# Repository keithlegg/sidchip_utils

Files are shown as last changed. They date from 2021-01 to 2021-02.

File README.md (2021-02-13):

# sidchip_utils

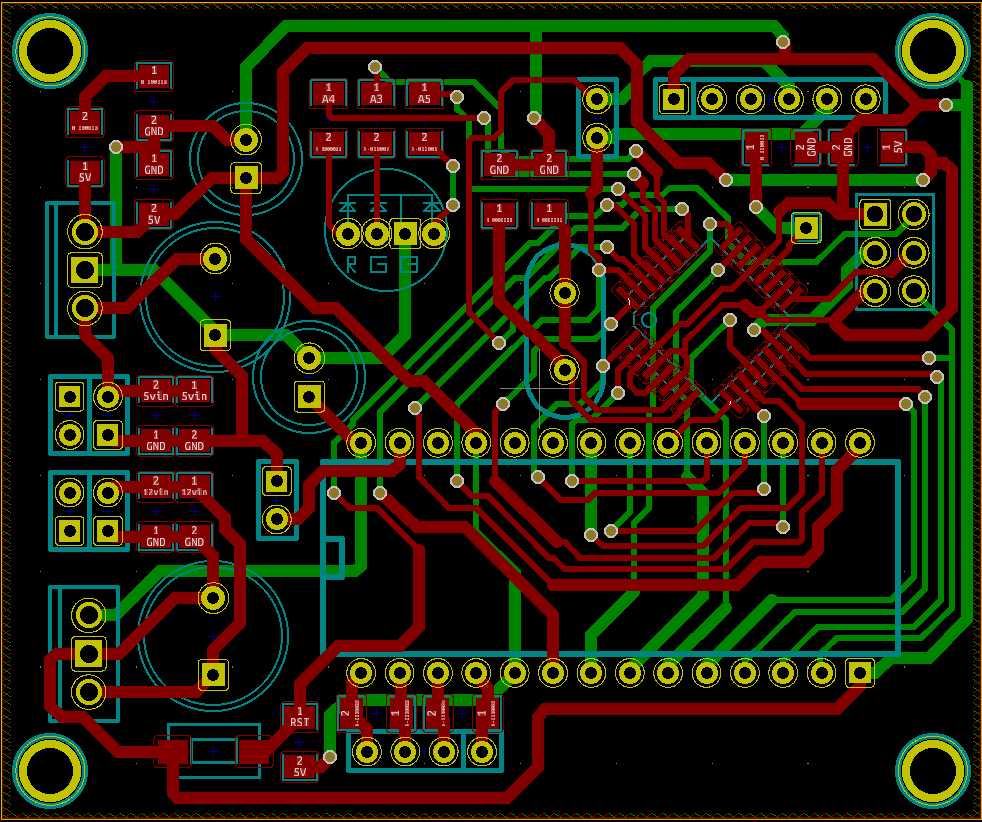
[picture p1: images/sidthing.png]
 

If you ever get the chance to purchase 30 rusty old SID chips from an engineer who worked at Commodore .... 

DONT DO IT! Put your energy into something else.  

This a small collection of tools, references files, and errata making those old chips sing.

What it is:

siduino           - Kicad project / Gerbers 
                    A one off PCB design thats an arduino (atmega328p) that has a SID chip on it 
                    technically you could program it with the arduino tools if you mapped the pins out properly, but I havent tried it has a 12V and 5V power bus to satisfy the analog-y power needs of the old chips. They run hot. 

siduino firmwware - AVR firmware to issue commands to the SID chip from an AtMega328. 
                    There is some experimental assembly language driver and some experimental midi in/out.  

sidcom            - unfinished. A aerial protocol to talk to the SID chip from a modern machine. The board is flawed, the TX/RX
                    pins on the AVR share the lower two bits of the SID chip data bus, so a new board is needed before this can be used. A prototype board is under development. 

python tools      - Havent done anything yet. The RX/TX flaw really makes this board suck. I need to build a better one 
                    with a bigger chip and two SIDs for stereo. maybe someday. 

If you are crazy enough to want to build one yourself (beware this revision has the TX/RX flaw): 

https://oshpark.com/profiles/klegg

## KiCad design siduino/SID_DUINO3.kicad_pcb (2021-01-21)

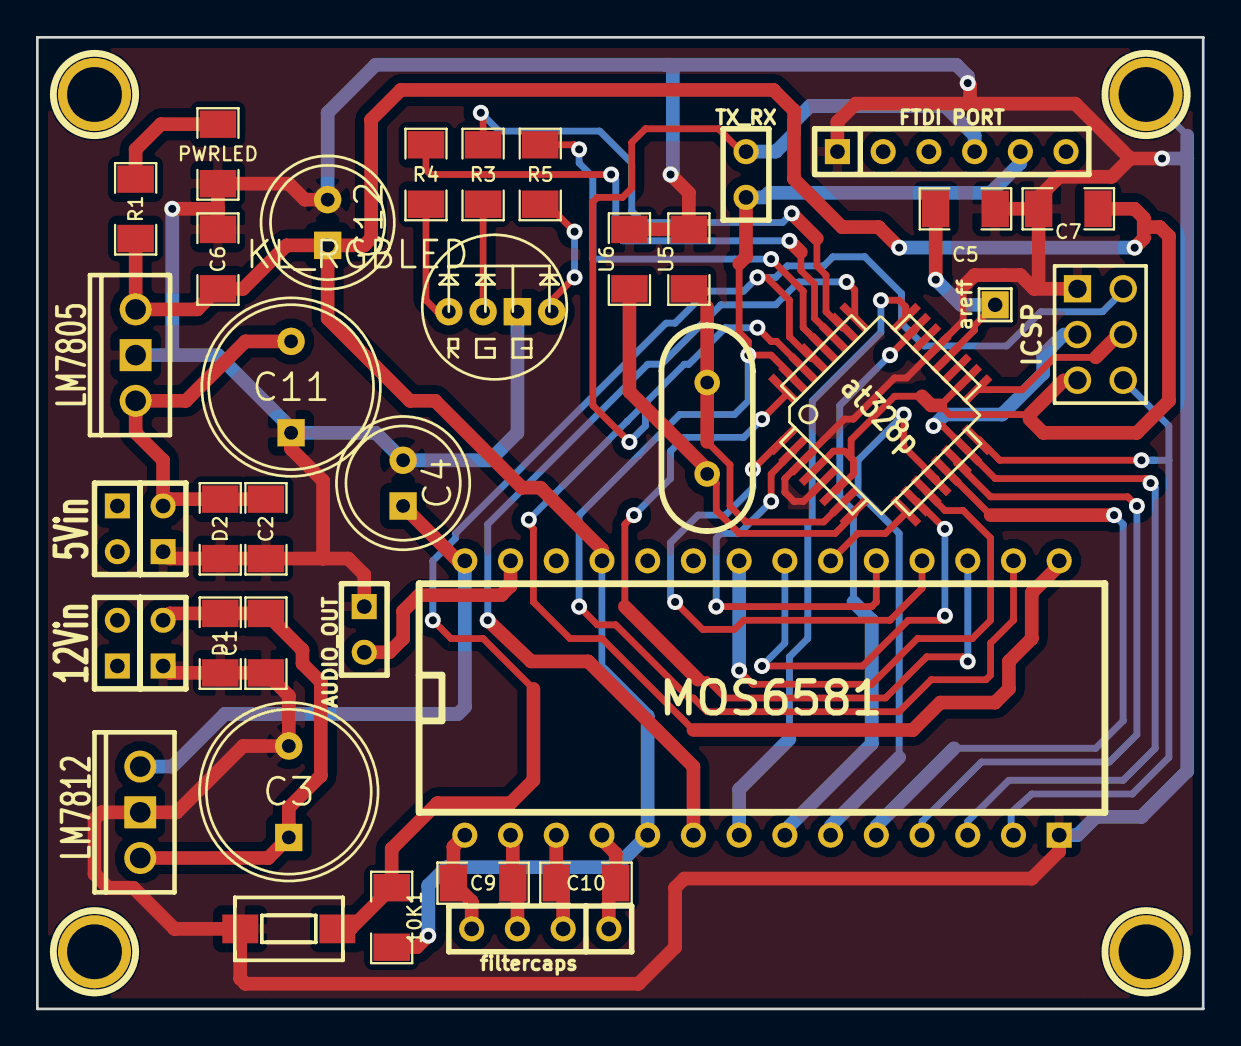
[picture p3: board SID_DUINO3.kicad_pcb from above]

Board: 2 copper layers, 64.8 x 54.0 mm, 30 parts (0 on the bottom side), 21 nets.

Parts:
5Vin: 5V_IN; SIL-2
10K1: R; SM1206
12Vin: 12V_IN; SIL-2
AUDIO_OUT: AudioOut; SIL-2
C1, C2, C5, C9, C10: C; SM1206
C3, C11: KL_330uf
C4, C12: KL_100uf
C6: .1uf; SM1206
C7: 4.7uf; SM1206
D1, D2: DIODE; SM1206
FTDI PORT: FTDI; SIL-6
ICSP: ICSP; pin_array_3x2
PWRLED: LED; SM1206
R1, R3, R4, R5: R; SM1206
TX_RX: UART; SIL-2
U5, U6: 18pf; SM1206
areff: CONN_1; SIL-1
at328p: TQFP32
filtercaps: Val**; SIL-4

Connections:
/5V: 10K1.2, C6.2, C7.1, C12.1, ICSP.2, R1.1, at328p.4, at328p.6, at328p.18
/5vin: 5Vin.2, C2.1, C11.1, D2.2
/12vin: 12Vin.2, C1.1, C3.1, D1.2
/A3: R3.1, at328p.26
/A4: R4.1, at328p.27
/A5: R5.1, at328p.28
/D11: ICSP.4, at328p.15
/D12: ICSP.1, at328p.16
/D13: ICSP.3, at328p.17
/RST: 10K1.1, ICSP.5, at328p.29
/RX_D1: FTDI PORT.5, TX_RX.1, at328p.31
/TX_D0: FTDI PORT.4, TX_RX.2, at328p.30
GND: 5Vin.1, 12Vin.1, AUDIO_OUT.1, C1.2, C2.2, C3.2, C4.2, C5.2, C6.1, C7.2, C11.2, C12.2, D1.1, D2.1, FTDI PORT.1, ICSP.6, PWRLED.2, U5.2, U6.2, at328p.3, at328p.5, at328p.21
unnamed: C5.1, areff.1, at328p.20
unnamed: PWRLED.1, R1.2
unnamed: C10.1, filtercaps.1
unnamed: C9.1, filtercaps.3
unnamed: C10.2, filtercaps.2
unnamed: C9.2, filtercaps.4
unnamed: U5.1, at328p.7
unnamed: U6.1, at328p.8

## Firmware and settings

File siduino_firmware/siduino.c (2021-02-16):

#include "sid_ctrl.h"

//extern volatile unsigned long timenow; //test 

unsigned long lastupdate = 0; //test 

extern volatile bool running;

/***************************************************/

/*

PORTD - DATA 
PORTC - 

C5 - RGB
C4 - RGB
C3 - RGB 

*/


//OLD STANDBY external no divide by eight
//sudo avrdude -V -c usbtiny -p atmega328p  -U lfuse:w:0xff:m -U hfuse:w:0xd9:m 

//FUSE SETTINGS ??
//sudo avrdude -V -c usbtiny -p atmega328p  -U lfuse:w:0xde:m -U hfuse:w:0xd9:m  /----NO---->/ -U efuse:w:0xff:m 
//sudo avrdude -V -c usbtiny -p atmega328p  -U lfuse:w:0xde:m -U hfuse:w:0xd9:m -U efuse:w:0xff:m 


/*
    10 S=54272
    20 FOR L = 0 TO 24: POKE S+L,0: NEXT
    30 POKE S+1,10
    40 POKE S+5,10
    50 POKE S+15,255
    60 POKE S+24,100
    70 POKE S+4,33
    --------------------------
    POKE 54273,10   = 11010100-00000001, 00001010  -NOTE TO PLAY // xx273 and xx272 = high freq , low freq  
    POKE 54277,10   = 11010100-00000101, 00001010 - Attack Decay    - 255 is slowest attack
    POKE 54278,255  = 11010100-00000110, 11111111 - Attack Decay    - 255 is slowest attack
    POKE 54287,100  = 11010100-00001111, 01100100 - 
    POKE 54296,15   = 11010100-00011000, 00011111 - volume 15 is highest
    POKE 54276,33   = 11010100-00000100, 00100001

    void play_sound2()
    {
        //POKE 54273,10    - Note to play
        wrSID(0b00000001 , 0b00001010 );  
        //POKE 54277,10    - Attack Decay
        wrSID(0b00000101 , 0b00001010 );
        //POKE 54278,255    - Sustain Release
        wrSID(0b00000110 , 0b11111111 );
        //POKE 54287,100    -   
        wrSID(0b00001111 , 0b01100100 );
        //POKE 54296,15     - full volume 
        wrSID(0b00011000 , 0b00011111 );

        //wrSID(0b00000100 , 0b00010001 );//POKE54276,17      - triangle wave
        wrSID(0b00000100 , 0b00100001 );//POKE54276,33      - sawtooth wave

    }

*/


/***************************************************/

/*

  //FROM // http://www.oxyron.de/html/registers_sid.html
  ------------------------------------------------------------------------------------------------
                      7         6         5         4         3        2         1         0     
  ------------------------------------------------------------------------------------------------
   0  - $D400 - 54272 - (W) FREQLO1                          Channel 1 Frequency Low-Byte
   1  - $D401 - 54273 - (W) FREQHI1                          Channel 1 Frequency High-Byte
   2  - $D402 - 54274 - (W) PWLO1                            Channel 1 Pulse Width (PW7-0)
   3  - $D403 - 54275 - (W) PWHI1                     UNUSED              |       Channel 1 Pulse Width (PW11-8)
   4  - $D404 - 54276 - (W) CR1     NOISE  |   PULSE  |   SAW  |   TRI    |  TEST  |  RING  |   SYNC  |   GATE
   5  - $D405 - 54277 - (W) AD1             Channel 1 Attack              |       Channel 1 Decay
   6  - $D406 - 54278 - (W) SR1             Channel 1 Sustain             |       Channel 1 Release
   7  - $D407 - 54279 - (W) FREQLO2                          Channel 2 Frequency Low-Byte
   8  - $D408 - 54280 - (W) FREQHI2                          Channel 2 Frequency High-Byte
   9  - $D409 - 54281 - (W) PWLO2                            Channel 2 Pulse Width (PW7-0)
   10 - $D40A - 54282 - (W) PWHI2                     UNUSED              |       Channel 2 Pulse Width (PW11-8)
   11 - $D40B - 54283 - (W) CR2     NOISE  |   PULSE  |   SAW  |   TRI    |  TEST  |  RING  |   SYNC  |   GATE
   12 - $D40C - 54284 - (W) AD2             Channel 2 Attack              |       Channel 2 Decay
   13 - $D40D - 54285 - (W) SR2             Channel 2 Sustain             |       Channel 2 Release
   14 - $D40E - 54286 - (W) FREQLO3                         Channel 3 Frequency Low-Byte
   15 - $D40F - 54287 - (W) FREQHI3                         Channel 3 Frequency High-Byte
   16 - $D410 - 54288 - (W) PWLO3                           Channel 3 Pulse Width (PW7-0)
   17 - $D411 - 54289 - (W) PWHI3     unused                              | Channel 3 Pulse Width (PW11-8)
   18 - $D412 - 54290 - (W) CR3     NOISE  |   PULSE  |   SAW  |   TRI    | TEST   |   RING |   SYNC  |   GATE
   19 - $D413 - 54291 - (W) AD3              Channel 3 Attack             |       Channel 3 Decay
   20 - $D414 - 54292 - (W) SR3              Channel 3 Sustain            |       Channel 3 Release
   21 - $D415 - 54293 - (W) FCLO             unused                       |       Filter Cutoff Low (FC2-FC0)
   22 - $D416 - 54294 - (W) FCHI      Filter Cutoff High (FC10-FC3)
   23 - $D417 - 54295 - (W) Res/Filt  Filter Resonance  Filt Ex   Filt 3  Filt 2                           Filt 1
   24 - $D418 - 54296 - (W) Mode/Vol  Ch3Off    HighPass  BandPass  LoPass|             Volume
   25 - $D419 - 54297 - (R) POTX                        Potentiometer X
   26 - $D41A - 54298 - (R) POTY                        Potentiometer Y
   27 - $D41B - 54299 - (R) OSC3                        Channel 3 Oscillator
   28 - $D41C - 54300 - (R) ENV3                        Channel 3 Envelope
  ------------------------------------------------------------------------------------------------

   The GATE bit controls the Envelope Generator. When this bit is set to 1, it triggers the Envelope Generator 
   and the ATTACK/DECAY/SUSTAIN cycle begins. When the bit is reset to zero, the RELEASE cycle begins. 
   Setting bits 4,5 or 6 to 1 selects that particular waveform.

*/


void play_spacechip()
{
  int x = 0;
  int delay = 2;
 
  for (x=0;x<20;x++)
  {
      wrSID(0b00000001 , 0b000101000); //POKE 54273, 40     - Note to play
      _delay_ms(delay);  

      wrSID(0b00000001 , 0b01010000); //POKE 54273, 80     - Note to play
      _delay_ms(delay); 

      wrSID(0b00000001 , 0b01100100); //POKE 54273, 100     - Note to play
      _delay_ms(delay); 
      
      wrSID(0b00000001 , 0b01111000); //POKE 54273, 120     - Note to play
      _delay_ms(delay); 
      
      wrSID(0b00000001 , 0b10001100); //POKE 54273, 140     - Note to play
      _delay_ms(delay); 
     
      wrSID(0b00000001 , 0b10100000);  //POKE 54273, 160     - Note to play
      _delay_ms(delay);
  } 
}

/***************************************************/

//FILTERS
/*

30 POKE 54296,31  : REM FULL VOLUME PLUS LOW PASS FILTER
35 POKE 54295,1   : REM SELECT FILTER FOR VOICE 1
37 POKE 54294,128 : POKE 54293,7  : REM SELECT CUTOFF FREQUENCY
// 
50 pokes+10,8:pokes+22,128:pokes+23,244

*/

void test_filters()
{
    int delay     = 100;
    int num_loops = 4;

    //wrSID(0b00011000 , 0b00001111 ); // Set maximum Volume
    wrSID(0b00011000 , 0b00001111 );   // 54296,31  FULL VOLUME PLUS LOW PASS FILTER
    wrSID(0b00000100 , 0b00100001 );   // 54276,33  - sawtooth wave

    /************/
    wrSID(0b00010111 , 0b00000000 );   // 54295,0  - Voice 1 filter enable
    
    wrSID(0b00010101 , 0b00000010 );   // (l) 54293,0  - cutoff filter 0-2 
    wrSID(0b00010110 , 0b00000111 );   // (h) 54293,0  - cutoff filter 0-7 
    
    //wrSID(0b00010111 , 0b00000100 );   //     54295,0  - resonance filter 4-7 

    //wrSID(0b00010111 , 0b00000100 );   //     54296,4  - low pass filter
    //wrSID(0b00010111 , 0b00000101 );   //     54296,5  - band pass filter
    //wrSID(0b00010111 , 0b00000110 );   //     54296,6  - high pass filter    

    wrSID(0b00000001 , 0b01000000); // 54273, 40     - Note to play

    for (int x= 0;x<num_loops;x++)
    {
        wrSID(0b00010111 , 0b00000100 );   //     54295,0  - resonance filter 4-7 
        //wrSID(0b00010111 , 0b00000100 );   //     54296,4  - low pass filter      
        _delay_ms(delay);  

         wrSID(0b00010111 , 0b00000101 );   //     54295,0  - resonance filter 4-7 
        //wrSID(0b00010111 , 0b00000101 );   //     54296,5  - band pass filter        
        _delay_ms(delay); 

         wrSID(0b00010111 , 0b00000111 );   //     54295,0  - resonance filter 4-7 
        //wrSID(0b00010111 , 0b00000110 );   //     54296,6  - high pass filter  
        _delay_ms(delay); 
        

    }


}

/***************************************************/

void voice1_scale()
{

      int delay     = 10;
      int num_loops = 2;

      wrSID(0b00000100, 0b00010001 );// 54276,17      - triangle wave

      for (int x= 0;x<num_loops;x++)
      {
      
        wrSID(0b00000001, 0b000101000); // 54273, 40     - Note to play
        _delay_ms(delay);  

        wrSID(0b00000001, 0b01010000); // 54273, 80     - Note to play
        _delay_ms(delay); 

        wrSID(0b00000001, 0b01100100); // 54273, 100     - Note to play
        _delay_ms(delay); 
        
        wrSID(0b00000001, 0b01111000); // 54273, 120     - Note to play
        _delay_ms(delay); 
        
        wrSID(0b00000001, 0b10001100); // 54273, 140     - Note to play
        _delay_ms(delay); 
       
        wrSID(0b00000001, 0b10100000);  // 54273, 160     - Note to play
        _delay_ms(delay); 
    }

      
      wrSID(0b00000100, 0b00100001 );//54276,33      - sawtooth wave

      for (int x= 0;x<num_loops;x++)
      {
        wrSID(0b00000001, 0b000101000); // 54273, 40     - Note to play
        _delay_ms(delay);  

        wrSID(0b00000001, 0b01010000); // 54273, 80     - Note to play
        _delay_ms(delay); 

        wrSID(0b00000001, 0b01100100); // 54273, 100     - Note to play
        _delay_ms(delay); 
        
        wrSID(0b00000001, 0b01111000); // 54273, 120     - Note to play
        _delay_ms(delay); 
        
        wrSID(0b00000001, 0b10001100); // 54273, 140     - Note to play
        _delay_ms(delay); 
       
        wrSID(0b00000001, 0b10100000);  // 54273, 160     - Note to play
        _delay_ms(delay); 
    }


}

/***************************************************/

void voice2_scale()
{

      int delay     = 3;
      int num_loops = 255;

      //wrSID(0b00001011, 0b00100001 );// 54283,33  - sawtooth wave
      //wrSID(0b00001011, 0b00100001 );// 54283,17  - triangle wave
     
      //wrSID(0b00001000, 0b00001000 );  //54280  - pulse width (l)     
      //wrSID(0b00001001, 0b00001000 );  //54281  - pulse width (h)


      //MULTI VOICE TEST 
      //wrSID(0b00000001, 0b00110000); // 54273,   - voice1 Note to play

      // wrSID(0b00000111, 0b10000010 ); // (l) 54279       - Set Frequency of voice 2
      // wrSID(0b00001000, 0b00101000 ); // (h) 54280, 40   - Note to play
      // _delay_ms(delay);  

      for (int x= 0;x<num_loops;x++)
      {
        //wrSID(0b00001000, 0 );  //54280  - pulse width (l)     
        //wrSID(0b00001001, x );  //54281  - pulse width (h)
        _delay_ms(delay); 
       
        //wrSID(0b00001000, 0b00100000 );  //54280  - pulse width (l)     
        //wrSID(0b00001001, 0b00100000 );  //54281  - pulse width (h)

      }

}


/***************************************************/

void sweep_freqency_v1()
{
    int delay = 5;
    int steps = 255;

    wrSID(0b00011000, 0b00001111 ); // Set maximum Volume
    
    //wrSID(0b00000100, 0b00010001 );// 54276,17      - triangle wave
    wrSID(4, 17 );// 54276,17      - triangle wave

    int x,y = 0;

    //DEBUG does not work 
    //for (x = 0;x<steps;x++)
    //{
    //    for (y= 0;y<steps;y++)
    //    {
    //      poke(0,y);poke(1,x);
    //      _delay_ms(delay); 
    //    }
    //}

    for (int x= 0;x<steps;x++)
    {
      wrSID(1,x);//1 is HIGH register (zero indexed) 
      _delay_ms(delay); 
    }
      

}

/***************************************************/

void sweep_pulse_width_v1()
{
    int delay = 20;//ms 
    int steps = 255;

    wrSID(0b00011000, 0b00001111 ); // Set maximum Volume
 
    //wrSID(1, 40); // ,   - voice1 Note to play

    for (int x= 0;x<steps;x++)
    {

      //wrSID(2, 0 );  // 54274  - pulse width (l)     
      wrSID(3, x );  // 54275  - pulse width (h)

      _delay_ms(delay); 
    }
      

}


/***************************************************/


//used as a hello user and to test RGB led connections
void test_leds(void){

   int a = 0;
   for (a=0;a<5;a++)
   {
      PORTC &= ~(0x38);;  //all LEDS off (pc3,pc4,pc5) 
      PORTC |= (0x8); //pc3 on - green  
      _delay_ms(10); 

      PORTC &= ~(0x38);;  //all LEDS off 
      PORTC |= (0x10); //pc4 on - blue  
      _delay_ms(10);

      PORTC &= ~(0x38);;  //all LEDS off 
      PORTC |= (0x20); //pc5 on - red 
      _delay_ms(10); 

      PORTC &= ~(0x1c);;  //all LEDS off  
   }
}

/***************************************************/
//sweep the address port to test bits are connected
void test_addr_bus(void){

   int a = 0;
   for (a=0;a<5;a++){
      PORTB = 0x00;  //bus off 
      PORTB = 0x1;   
      _delay_ms(50); 

      PORTB = 0x00;  //bus off 
      PORTB = 0x2;   
      _delay_ms(50); 

      PORTB = 0x00;  //bus off 
      PORTB = 0x4;   
      _delay_ms(50); 

      PORTB = 0x00;  //bus off 
      PORTB = 0x8;   
      _delay_ms(50); 

      PORTB = 0x00;  //bus off 
      PORTB = 0x10;   
      _delay_ms(50); 

      PORTB = 0x00;  //bus off 
      PORTB = 0x20;   
      _delay_ms(50); 

      PORTB = 0x00;  //bus off 
      PORTB = 0x40;   
      _delay_ms(50); 

      PORTB = 0x00;  //bus off 
      PORTB = 0x80;   
      _delay_ms(50);  
           
      PORTB = 0x00;  //bus off 
   }


}

/***************************************************/
//sweep the address port to test bits are connected
void test_data_bus(void){

   int a = 0;
   for (a=0;a<5;a++){
      PORTD = 0x00;  //bus off 
      PORTD = 0x1;   
      _delay_ms(50); 

      PORTD = 0x00;  //bus off 
      PORTD = 0x2;   
      _delay_ms(50); 

      PORTD = 0x00;  //bus off 
      PORTD = 0x4;   
      _delay_ms(50); 

      PORTD = 0x00;  //bus off 
      PORTD = 0x8;   
      _delay_ms(50); 

      PORTD = 0x00;  //bus off 
      PORTD = 0x10;   
      _delay_ms(50); 

      PORTD = 0x00;  //bus off 
      PORTD = 0x20;   
      _delay_ms(50); 

      PORTD = 0x00;  //bus off 
      PORTD = 0x40;   
      _delay_ms(50); 

      PORTD = 0x00;  //bus off 
      PORTD = 0x80;   
      _delay_ms(50);  
           
      PORTD = 0x00;  //bus off 
      } 
}

/***************************************************/
void setup_sid_voices()
{

    // 17= TRIANGLE , 33= SAW, 65= PULSE, 129= NOISE 

    //********************** setup SID parameters   *************************
    // SET GLOBAL VOLUME 
    
    //wrSID(0b00011000, 0b00001111 );       // (24) 54296, 15  Set maximum Volume
    //wrSID(0b00011000, 15 );               // (24) 54296, 15  Set maximum Volume
 
    //********************** Voice 1 parameters   *************************
      // OSCILLATOR  SETUP
      wrSID(0b00000000, 0b000000000);       // (0) 54272, 0    - low  inital frequency
      wrSID(0b00000001, 0b000100000);       // (1) 54273, 32   - high inital frequency
      //Voice1 ADSR *****
      wrSID(0b00000101, 0b00001001 );       // (5) 54277       - Set Attack/Decay voice 1
      wrSID(0b00000110, 0b10000000 );       // (6) 54278       - Set Sustain/Release voice 1
      //**** Voice1 WAVE ENABLE  *****
      wrSID(0b00000100, 0b00010001 );       // (4) 54276,17    - V1 Triangle waveform and Gate bits 
      //wrSID(0b00000100, 0b00100001 );     // (4) 54276,33    - V1 Sawtooth waveform and Gate bits 
      //wrSID(0b00000100, 0b01000001 );     // (4) 54276,65    - V1 Pulse waveform and Gate bits
      //wrSID(0b00000100,    );             // (4) 54276,128   - V1 Noise waveform and Gate bits
      // these only work with pulse type?      
      wrSID(0b00000010, 0b00000010 );       // (2) 54274       - pulse width (l)     
      wrSID(0b00000011, 0b00001000 );       // (3) 54275       - pulse width (h)
      //**** V1 ENVELOPE SETUP******** 
      //**** V1 FILTER SETUP ********* 

    //********************** Voice 2 parameters   *************************
    
      wrSID(0b00000111, 0b000000000);       // (7) 54279, 0    - Set inital frequency
      wrSID(0b00001000, 0b000101000);       // (8) 54280, 40   - Set inital frequency
      // wrSID(0b00001011, 0b01000001 );    // (11) 54283,65     CR - enable tone by setting waveform
      wrSID(0b00001100, 0b00001001 );       // (12) 54284        Set Attack/Decay voice 2
      wrSID(0b00001101, 0b10000000 );       // (13) 54285        Set Sustain/Release voice 2
      //wrSID(0b00001011, 0b00010001 );     // (11) 54290,17   - V2 Triangle waveform and Gate bits 
      //wrSID(0b00001011, 0b00100001 );     // (11) 54290,33   - V2 Sawtooth waveform and Gate bits 
      wrSID(0b00001011, 0b01000001 );       // (11) 54290,65   - V2 Pulse waveform and Gate bits 
      // these only work with pulse type?
      wrSID(0b00001001, 0b00000010 );       // (9) 54281       - pulse width (l)
      wrSID(0b00001010, 0b00001000 );       // (10) 54282      - pulse width (h)
    
   
    //********************** Voice 3 parameters   *************************
      wrSID(0b00001110, 0b000000000);       // (14) 54286,0    - Set inital frequency
      wrSID(0b00001111, 0b000101000);       // (15) 54286,40   - Set inital frequency
      //wrSID(0b00010010, 0b01000001 );     // (18) 54290,65     CR - enable tone by setting pulse ?
      wrSID(0b00010011, 0b00001001 );       // (19) 54291        Set Attack/Decay voice 3
      wrSID(0b00010100, 0b10000000 );       // (20) 54292        Set Sustain/Release voice 3
      //wrSID(0b00010010, 0b00010001 );     // (18) 54290,17   - V2 Triangle waveform and Gate bits 
      //wrSID(0b00010010, 0b00100001 );     // (18) 54290,33   - V2 Sawtooth waveform and Gate bits 
      wrSID(0b00010010, 0b01000001 );       // (18) 54290,65   - V2 Pulse waveform and Gate bits 
      wrSID(0b00010000, 0b00000010 );       // (16) 54280      - pulse width (l)     
      wrSID(0b00010001, 0b00001000 );       // (17) 54281      - pulse width (h)


}





void poketest(void)
{
    // 10 FOR L=54272 TO 54296:POKE L,0:NEXT Clears the SID chip
    // 20 POKE 54296,15  Set maximum volume
    // 30 POKE 54277,64  Set ATTACK/DECAY
    // 40 POKE 54273,162:POKE 54272,37 POKE one note in voice 1
    // 50 PRINT"PRESS ANY KEY" Screen message
    // 60 GET K$:IF K$="" THEN 60  Check the keyboard
    // 70 POKE 54276,17:FOR T=1 TO 200:NEXT  Start triangle waveform
    // 80 POKE 54276,16:FOR T=1 TO 50:NEXT Stop note
    // 90 GOTO 50


    // VOICE1 //-------------------------------------------- 
    poke( 54296 ,15  );    //  Set maximum volume
    poke( 54277 , 240  );  //  Set ATTACK/DECAY
    poke( 54278 , 240  );  //  Set SUSTAIN/RELEASE
    poke( 54273 , 50 );    //
    poke( 54272 , 0  );    // POKE one note in voice 1
    poke( 54274 , 203  );  //pulse width 
    poke( 54276 ,65  );    //choose pulse type and set gate bit (first bit is gate 0x1)
    // //  wrSID(4,65  );  //same poke, expressed as a direct register write 
    
    // VOICE2 //--------------------------------------------
    poke( 54296 ,15  );    //  Set maximum volume
    poke( 54285 , 240  );  //  Set SUSTAIN/RELEASE
    poke( 54284 , 240  );  //  Set ATTACK/DECAY
    poke( 54280 , 162 );   //    
    poke( 54279 , 100  );  // POKE one note in voice 1
    poke( 54281 , 0  );    // pulse width 
    poke( 54282 , 50  );   // pulse width 
    poke( 54283 , 33  );   // choose pulse type and set gate bit (first bit is gate 0x1)

    // VOICE3 //--------------------------------------------
    poke( 54296 ,15  );    //  Set maximum volume
    poke( 54291 , 240  );  //  Set ATTACK/DECAY
    poke( 54292 , 240  );  //  Set SUSTAIN/RELEASE
    poke( 54286 , 0  );  // POKE one note in voice 1
    poke( 54287 , 255 );   //
    poke( 54288 , 203  );  //pulse width 
    poke( 54290 , 65  );   // choose pulse type and set gate bit (first bit is gate 0x1)

    // poke(54276,16); //stop voice1
    // poke(54283,16); //stop voice2
    // poke(54290,16); //stop voice3

}
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
int main (void)
{


    enable_timer_isr(); //activate timer interrupt to pulse SID clock pin 
    init_SID_bus();     //setup AVR ports to send commands to  SID 
    sid_clear_registers(); //poke 53272+24,0 

    
    //setup_sid_voices();
    
    // test_leds();     // alert user we are online and ready to play
    //test_addr_bus(); // flash each bit in address bus

    // VOICE1 //-------------------------------------------- 
    poke( 54296 , 15  );    //  Set maximum volume
    poke( 54277 , 240  );  //  Set ATTACK/DECAY
    poke( 54278 , 100  );  //  Set SUSTAIN/RELEASE

    poke( 54272 , 200  );    // POKE one note in voice 1
    poke( 54273 , 150 );     // POKE one note in voice 1
   
    poke( 54274 , 153  );   // pulse width 
    poke( 54276 , 65  );    // choose waveform type and set gate bit (first bit is gate 0x1)
    

    /* 
    // // VOICE2 //--------------------------------------------
    poke( 54296 , 15  );    //  Set maximum volume
    poke( 54285 , 240  );  //  Set SUSTAIN/RELEASE
    poke( 54284 , 240  );  //  Set ATTACK/DECAY
    poke( 54280 , 162 );   //    
    poke( 54279 , 100  );  // POKE one note in voice 2
    poke( 54281 , 0  );    // pulse width 
    poke( 54282 , 50  );   // pulse width 
    poke( 54283 , 65  );   // choose waveform type and set gate bit (first bit is gate 0x1)
    

    // VOICE3 //--------------------------------------------
    poke( 54296 , 15  );   //  Set maximum volume
    poke( 54291 , 240  );  //  Set ATTACK/DECAY
    poke( 54292 , 240  );  //  Set SUSTAIN/RELEASE
    poke( 54286 , 0  );    // POKE one note in voice 3
    poke( 54287 , 255  );  //
    poke( 54288 , 203  );  // pulse width 
    poke( 54290 , 65  );   // choose waveform type and set gate bit (first bit is gate 0x1)
    */

   while(1)
   {
    
      sweep_pulse_width_v1();
      
      //sweep_freqency_v1();

      //test_notecmd();

      //poketest();

      //poketest2();

      //voice_ring_test();

      //voice_sync_test();

   }



 

} 

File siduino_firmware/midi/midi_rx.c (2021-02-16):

#include <avr/io.h>
#include <avr/interrupt.h>

// #define BAUD_PRESCALE (((F_CPU / (USART_BAUDRATE * 16UL))) - 1) 


#define F_CPU 16000000      // 16MHz 
#define BAUD 31250          // 31.250 KBaud is Baud Rate or Bit Rate
#define MYUBRR 31           // UART Baud Rate Register (UBRR) = (F_CPU/16/BAUD)-1


#define PWM_PIN 0x04 //PORTC
#define RW_PIN 0x02  //PORTC
#define CS_PIN 0x01  //PORTC

int set_PORTC_bit(unsigned int, unsigned int);
void USART_Init(unsigned int);
unsigned char USART_ReceiveByte(void);
void USART_TransmitByte(unsigned char);
void delay_ms(uint16_t x); // general purpose delay

#define sbi(a, b) (a) |= (1 << (b))
#define cbi(a, b) (a) &= ~(1 << (b))


/*
//draw a byte with two pins to look at with logic analyzer
void blink_byte_msb(uint8_t data)
{
    uint8_t i = 0;
    for (i=0; i<=7; i++) 
    {
        PORTB ^= _BV(3);   
        //if ( !!(data & (1 << ii)) ){  // LSB
        if ( !!(data & (1 << (7 - i))) ){  // MSB
            PORTC = 0x08; //ON
            sbi(PORTB, 4); 
        }else{
            PORTC = 0x00; //OFF
            cbi(PORTB, 4); 
        }
        PORTB ^= _BV(3);   
        delay_ms(10);
    }

    cbi(PORTB, 4); //leave data "off" 

}
*/

//draw a byte with two pins to look at with logic analyzer
void blink_byte_lsb(uint8_t data)
{
    uint8_t i = 0;
    for (i=0; i<=7; i++) 
    {
        PORTB ^= _BV(3);   
        //if ( !!(data & (1 << ii)) ){  // LSB
        if ( !!(data & (1 << (7 - i))) ){  // MSB
            PORTC = 0x08; //ON
            sbi(PORTB, 4); 
        }else{
            PORTC = 0x00; //OFF
            cbi(PORTB, 4); 
        }
        PORTB ^= _BV(3);   
        delay_ms(10);
    }

    cbi(PORTB, 4); //leave data "off" 

}





/************************************************************/
/************************************************************/
// interrupt section 
 
//use interrupt to setup SID clock pin as an audio source  
void enable_audio_isr()
{
    TCCR1B |= (1 << WGM12 ) ;  // Configure timer 1 for CTC mode
    TIMSK1 |= (1 << OCIE1A ) ; // Enable CTC interrupt
    sei();       //Enable global interrupts
    OCR1A = 0;    // Set CTC compare value - use to set tone of sound/delay 
    TCCR1A |= (1 << COM1A0);   // Toggle OC1A on Compare Match.
    
    TCCR1B |= (1 << CS10);     // clock on 
    TCCR1B |= (1 << CS12);     // clock on 

}

ISR ( TIMER1_COMPA_vect )
{
    PORTC ^= PWM_PIN; //XOR the system clock when not loading data to chip      
}


 
/************************************************************/
/************************************************************/



int main(void)
{
    
    USART_Init(MYUBRR);

    //DDRB = 0b11101111;    //PB4 = MISO 


    DDRC = 0xff;

        
    //Startup Test Sequence
    // PORTC = 0b0001;
    // delay_ms(800);
    // PORTC = 0b0011;
    // delay_ms(800);
    // PORTC = 0b0111;
    // delay_ms(800);
    // PORTC = 0b1111;
    // delay_ms(1600);
    // PORTC = 0b0000;
      

    //blink_byte_lsb(0xff);
     blink_byte_lsb(0xaa);
    // blink_byte_lsb(0x55);
    // blink_byte_lsb(0xf0);
    // blink_byte_lsb(0x0f);

    //enable_audio_isr();

    
    for(;;)
    {
       
        uint8_t byte = USART_ReceiveByte();
        if( byte !=0 )
        {
            PORTC = 0x10; //ON
            delay_ms(1);
            PORTC = 0x00; //OFF

            // blink_byte_lsb(byte);
            // PORTB = 0x00;
            // PORTC = 0x00;
            // delay_ms(20);
            
            if(byte==0x90)
            {
                // blink_byte_lsb(0xf0);

            }   
            
            //OCR1A = (uint8_t) byte/3;

            /*
            //AUDIO OUT TEST 
            if(byte==0x24)
            {
                OCR1A = 10;
            } 
            if(byte==0x25)
            {
                OCR1A = 9;
            } 

            if(byte==0x26)
            {
                OCR1A = 8;
            } 
            if(byte==0x27)
            {
                OCR1A = 7;
            } 
            if(byte==0x28)
            {
                OCR1A = 6;                
            }  
            */

            //BLINK OUT TEST 
            if(byte==0x24)
            {
                blink_byte_lsb(0x0f);
            } 
            if(byte==0x25)
            {
                blink_byte_lsb(0x0f);
            } 

            if(byte==0x26)
            {
                blink_byte_lsb(0xaa);
            } 
            if(byte==0x27)
            {
                blink_byte_lsb(0xaa);
            } 
            if(byte==0x28)
            {
                blink_byte_lsb(0x55);
            }  

        }
      
    }
  


    return 0;   /* never reached */
}


int set_PORTC_bit(unsigned int position, unsigned int value)      
{                                                                 

    // Function sets or clears the PORTC bit in position 'position'
    // either high or low (1 or 0) to match 'value'.
    
    // Leaves all other bits  unchanged.
    if (value == 0)
    {
        PORTC &= ~(1 << position);      // Set bit # 'position' low
    }
    else
    {
        PORTC |= (1 << position);       // Set bit # 'position' high
    }
    return 1;
}



void USART_Init(unsigned int ubrr_value)   //Initializes the Universal A/Synchonous Receiver/Transmitter
{
    
    //UBRR0 = (unsigned char) ubrr_value;                  
    //Sets the Baud/Bit rate
    
    UBRR0L = (unsigned char) ubrr_value;
    //Load lower 8-bits of the baud rate value  
    //into the low byte of the register
    
    UBRR0H = (unsigned char) (ubrr_value >> 8);            
    // Load upper 8-bits of the baud rate value 
    //into the high byte of the register
        
    UCSR0C |=  (1 << UCSZ01) | (1 << UCSZ00) ;                  
    
    /*
    //Note: MIDI uses 1 start bit, 8 data bits, and 1 stop bit, so 10 bits total per message
    //Set data frame format: asynchronous mode,no parity, 1 stop bit, 8 bit size
    
    //UCSR0C |= (0<<UMSEL00)|(0<<UMSEL01)|(0<<UPM01)|(0<<UPM00)|(0<<USBS0)|(0<<UCSZ02)|(1<<UCSZ01)|(1<<UCSZ00); 
    */
       
    UCSR0B = ( (1<<RXEN0) | (1<<TXEN0) );           //Enable The receiver and  transmitter
    
    
}


unsigned char USART_ReceiveByte( void ){            
    
    //This function is used to read the available data from USART. 
        
    while( !(UCSR0A & (1<<RXC0)) )          //Wait until data is available
        
        //Do nothing until data have been recieved and is ready to be read 
        //from UDR (wait until data is received)
        
        ;//(Do nothing)
    
    
    //Now USART has received data from host
    //and is available as a buffer
    
    return UDR0;
}
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

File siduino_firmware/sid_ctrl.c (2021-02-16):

#include "sid_ctrl.h"

volatile bool running = false;

//volatile unsigned long timenow = 0; //test 

/*
 ****************************************************************
 SIDUINO - MEGA328P  Pin Mapping 

 CLK         - PC2 0x04 - data read when high 
 RW          - PC1 0x02 - RW stays low (DDR -> SID reads data)
 CS          - PC0 0x01 - data read when low
 RGBLED      - PC4,PC5,PC6 (0x08, 0x10, 0x20)

 Address bus - portB
 Data bus    - portD
 ****************************************************************

    For example:

    POKE 54273,255

    would look like this in binary:

    POKE 1101010000000001, 11111111

    breaking down that address we get:

    11010100 00000001

    then "AND" masking the lower byte with 5 bits we get:

    00000001 -LOWER BYTE of C64 POKE. 00011111 -& 0x1f MASK. xxx00001 -The resulting address masked out

    not sure if this will ever work , but eventually if I get the timing correect I will add the 8 bit data port and put 3 DAC chips on the PCB to generate the 3 SID voices.

    One word of advice - make sure you are very carefull to set EVERY pin properly. All pins not in use MUST bin the HI-Z state or the commodore will flip out and maybe even be damaged. I haven't hurt mine yet however.

    Keith Legg April 12, 2014

 ****************************************************************

 SID WAVEFORM TYPES 
 17= TRIANGLE , 33= SAW, 65= PULSE, 129= NOISE 

 ****************************************************************
 
 SID-ADR-Table:

     VALUE    ATTACK    DECAY/RELEASE
   +-------+----------+---------------+
   |   0   |    2 ms  |      6 ms     |
   |   1   |    8 ms  |     24 ms     |
   |   2   |   16 ms  |     48 ms     |
   |   3   |   24 ms  |     72 ms     |
   |   4   |   38 ms  |    114 ms     |
   |   5   |   56 ms  |    168 ms     |
   |   6   |   68 ms  |    204 ms     |
   |   7   |   80 ms  |    240 ms     |
   |   8   |  100 ms  |    300 ms     |
   |   9   |  240 ms  |    720 ms     |
   |   10  |  500 ms  |    1.5 s      |
   |   11  |  800 ms  |    2.4 s      |
   |   12  |    1 s   |      3 s      |
   |   13  |    3 s   |      9 s      |
   |   14  |    5 s   |     15 s      |
   |   15  |    8 s   |     24 s      |
   +-------+----------+---------------+

 ****************************************************************
   SID-Maths:

    Frequency:
    ----------

     To calculate the frequency corresponding to the 16-bit value in
     $D400+$D401, $D407+$D408, $D40E+$D40F use the following formula:

      Freq = 16Bit-Value * Phi2 / 16777216 Hz

     where Phi2 is the system-clock, 985248 Hz for PAL-systems,
     1022727 Hz for NTSC-systems.

     A good approximation for both systems is the formula:

      Freq = 16Bit-Value / 17.03

    Pulse-Width:
    ------------

     To calculate the pulse width (in %) corresponding to the 12-bit value in
     $D402+$D403, $D409+$D40A, $D410+$D411 use the following formula:

      PulseWidth = (16Bit-Value / 40.96) %


 ****************************************************************

   Playing a sound:

      1. Set frequency and ADSR, and in case you use the pulse wave also set the pulse width.
      2. Set the waveform and the GATE bit in the control register. Setting the gate bit will start the ADSR envelope generator.
      3. Wait for as long as you wish the note to be played.
      4. Clear gate bit. This will start the release phase of the ADSR.
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
